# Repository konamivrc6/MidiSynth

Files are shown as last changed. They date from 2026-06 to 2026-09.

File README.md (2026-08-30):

# MidiSynth — ESP32-S3 MIDI 合成器

基于 ESP32-S3 的 12 复音双振荡器合成器，支持 USB MIDI 键盘输入、4 个硬件开关切换音色、串口实时调参。

## 硬件

| 模块 | 型号 | 接口 | 说明 |
|---|---|---|---|
| 主控 | ESP32-S3-DevKitC-1 (N16R8) | — | 双核 FreeRTOS |
| DAC | PCM5102 | I²S | 硬件模式，上电即工作 |
| 功放 | LM4881 | — | 纯硬件，无需代码控制 |
| 电位器 | — | ADC GPIO1 | 主音量调节 |
| 拨动开关 ×4 | — | GPIO10~13 | 二进制选择预设 (bit0~3) |
| 按钮 | — | GPIO14 | 加载当前开关对应的预设 |

### 引脚连接

```
I²S:   BCK → GPIO4,   LRCK → GPIO5,  DIN → GPIO6
ADC:   VR1 → GPIO1
开关:  SW1 → GPIO13 (bit0), SW2 → GPIO12 (bit1)
       SW3 → GPIO11 (bit2), SW4 → GPIO10 (bit3)
按钮:  BTN → GPIO14 (中断, FALLING)
```

所有开关和按钮使用 ESP32-S3 内部上拉，闭合时接 GND（低电平有效）。

## 软件架构

```
src/
├── config.h           # 全局类型定义、常量、extern 声明（所有 .inc 均包含此头文件）
├── config.inc         # 编译单元局部配置 + debugMode 定义（必须最先拼接）
├── presets.inc        # 16 种音色预设
├── audio_engine.inc   # 音频引擎（波形/包络/滤波器/复音管理/I²S 输出）
└── usb_midi.inc       # USB MIDI Host（接收外部 MIDI 键盘）
wavetables/
├── wavetables.h       # 分层波表常量与接口声明
├── wavetables.inc     # 自动生成的抗混叠波表数据（2048×11×6）
└── generate_wavetables.py  # 波表生成脚本
build.py               # 构建脚本（拼接 .inc → 单一 .cpp + 同步 config.h → .ino）
MidiSynth.ino          # Arduino 主文件（setup / loop / 串口命令）
```

### 音频引擎特性

- **双振荡器**：每个 Voice 包含 OSC1 + OSC2，可独立配置波形、音高倍数、音量、包络、滤波器路由
- **6 种波形**：Sine、Triangle、Pulse 1/8、Pulse 1/4、Pulse 1/2、Saw
- **ADSR 包络**：Attack / Decay / Sustain / Release，可独立配置 Attack 时间、Decay 时间、Sustain Level、Sustain 开关、Release 时间
- **双滤波器**：Filter1 高通 + Filter2 低通，一阶 IIR，可独立配置截止频率和强度
- **12 复音**：带智能 Voice 分配策略（同音符触发 Release → 空闲 → 衰减中 → 最早触发）
- **调试模式**：`debugMode` 变量控制启动信息、USB MIDI 诊断、性能报告的串口输出，可通过 `debug on/off` 切换，默认开启

## 依赖库

- **EspUsbHost** (by tanakamasayuki) — USB MIDI Host
- ESP32 Arduino Core（I²S、FreeRTOS）

## 构建

1. 修改 `src/` 下的源文件
2. 运行构建脚本：

```bash
python build.py                # 输出 MidiSynth_combined.cpp + 同步 config.h → .ino
python build.py -o out.cpp     # 输出到指定文件
python build.py --no-sync      # 仅拼接，不同步 .ino
```

3. 将 `MidiSynth.ino` 和 `MidiSynth_combined.cpp` 放在同一 Arduino 工程目录下
4. 用 Arduino IDE 编译上传

> **注意**：`build.py` 会自动将 `config.h` 中 `#define`/`enum`/`struct` 定义同步到 `.ino` 文件（匹配带有"(与 config.h 同步)"标记的区段）。修改 `config.h` 后运行 `build.py` 即可，无需手动同步。

## 使用

### 硬件操作

- **4 个拨动开关**：选择预设编号（二进制，SW1=bit0 ~ SW4=bit3，范围 0~15）
- **按钮**：加载当前开关对应的预设
- **电位器**：调节输出音量
- **右侧 USB**：连接 MIDI 键盘

### MIDI 文件播放

电脑端可通过串口将 `.mid` 文件实时发送给合成器播放。

**方式一：交互式播放器**

```bash
python play_midi.py
```

交互命令：

```
<数字>        播放对应编号的 MIDI 文件
port <COM号>  设置串口号 (如 port 3)
port auto     自动检测串口
port          列出所有可用串口
list          刷新 MIDI 文件列表
tempo <倍率>  播放速度倍率 (如 tempo 1.5)
trans <半音>  移调 (如 trans 12 升八度)
inst <0-15>   设置乐器预设
stop          发送 All Notes Off (紧急静音)
repeat <N> [次] 循环播放 (如 repeat 0 5)
/<命令>       发送原始串口命令 (如 /status)
help          显示帮助
quit / q      退出
```

MIDI 文件放在 `MIDI\` 目录下即可被自动扫描。

**方式二：命令行直接播放**

```bash
python MIDI\midi2serial.py <midi文件> [选项]

选项:
  --port COM3         串口输出
  --baud 115200       波特率 (默认 115200)
  --tempo 1.0         速度倍率
  --transpose N       移调 (半音)
  --preset N          乐器预设 0-15
  --save out.txt      将命令序列保存到文件
  --no-time           不显示时间戳

示例:
  python MIDI\midi2serial.py MIDI\song.mid --port COM3 --tempo 1.2
  python MIDI\midi2serial.py MIDI\song.mid --save cmds.txt  # 仅生成文件
```

### 串口命令（115200 baud）

```
note  <0-127> [vel=100]   — Note On（vel=0 即 Note Off）
off   <0-127>             — Note Off
preset <0-15>             — 加载预设

--- 振荡器参数 ---
o1wave <0-5>  o2wave <0-5>   — 波形: 0=Sine 1=Tri 2=P1/8 3=P1/4 4=P1/2 5=Saw
o1atk  <ms>    o2atk  <ms>    — Attack 时间 (ms)
o1sus  <0|1>   o2sus  <0|1>   — Sustain 开关
o1dec  <ms>    o2dec  <ms>    — Decay 时间 (ms)
o1slv  <0-1>   o2slv  <0-1>   — Sustain Level
o1rel  <ms>    o2rel  <ms>    — Release 时间 (ms)
o1vol  <0-1>   o2vol  <0-1>   — 音量
o1pm   <f>     o2pm   <f>     — 音高倍数 (2.0, 1.5, 1.0, 0.667, 0.5)
o1f1   <0|1>   o1f2   <0|1>   — OSC1 经 Filter1/2 路由
o2f1   <0|1>   o2f2   <0|1>   — OSC2 经 Filter1/2 路由

--- 滤波器参数 ---
hpfc <Hz>   hpfi <0-1>    — 高通截止频率 / 强度
lpfc <Hz>   lpfi <0-1>    — 低通截止频率 / 强度

--- 其他 ---
status                     — 打印当前参数
debug on/off               — 切换调试模式（控制启动日志/性能报告/USB诊断等输出）
help                       — 显示帮助
```

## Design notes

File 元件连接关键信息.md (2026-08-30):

* 去掉所有电阻、电容等无源器件后，**只保留与程序相关的关键连接**信息（含引脚编号、功能描述和必要的配置说明） *

## 一、主控芯片 ESP32‑S3（开发板 ESP32‑S3‑DevKitC‑1 N16R8）

### 1. I²S 音频输出（至 PCM5102 DAC）

```c
BCK  (位时钟)  → GPIO4
LRCK (左右时钟) → GPIO5
DIN  (数据)    → GPIO6
```

- PCM5102 工作在 **硬件模式**，无需 I²C 配置，只需 ESP32 端初始化 I²S 并连续发送 PCM 数据。

### 2. ADC 输入（电位器）

```c
VR1 滑动端 → GPIO1 (ADC1_CH0)
```

- 电位器两端分别接 3.3V 和 GND，模拟电压 0～3.3V，直接通过 `analogRead(1)` 读取（12 位 ADC 分辨率）。

### 3. 拨动开关（预设选择 ×4）

| GPIO | 网络名称 | 功能 | 软件配置 |
|---|---|---|---|
| GPIO13 | SW1 | 拨动开关 bit0 (值=1) | 输入模式，**使能内部上拉**（开关闭合接 GND） |
| GPIO12 | SW2 | 拨动开关 bit1 (值=2) | 输入模式，使能内部上拉 |
| GPIO11 | SW3 | 拨动开关 bit2 (值=4) | 输入模式，使能内部上拉 |
| GPIO10 | SW4 | 拨动开关 bit3 (值=8) | 输入模式，使能内部上拉 |

**读取示例：**

```cpp
uint8_t sw = 0;
if (!digitalRead(13)) sw |= 1;
if (!digitalRead(12)) sw |= 2;
if (!digitalRead(11)) sw |= 4;
if (!digitalRead(10)) sw |= 8;
// sw 范围 0~15，对应 16 种预设
```

### 4. 按钮（加载预设）

```c
按钮 → GPIO14
```

- 输入模式，**使能内部上拉**，按下为低电平。
- 配置为下降沿中断 (`FALLING`)，在中断服务中读取四个开关状态并加载对应预设。
- 软件消抖 200ms。

## 二、DAC 模块 PCM5102（纯硬件）

- **无需任何软件控制**，上电即工作。
- 使用的硬件接线：

`VCC` → 3.3V，`GND` → GND

`FLT`/`DMP`/`FMT` 已接地，`XMT`（静音）已接 3.3V（不静音）。

- 编程时只需关注 I²S 接口的 GPIO4/5/6。

## 三、耳机放大器 LM4881

- 纯硬件，**不需要代码控制**。

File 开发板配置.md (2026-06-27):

| 配置项 | 选择 |
|---|---|
| **USB CDC On Boot** | `Enabled` |
| **Flash Mode** | **`DIO`** |
| **Flash Size** | **`16MB`** |
| **PSRAM** | **`OPI PSRAM`** |
| **USB Mode** | `Hardware CDC and JTAG` |
| **Upload Mode** | `UART0 / Hardware CDC` |
| **Partition Scheme** | **`16M Flash (3M APP/9.9MB FATFS)`**|
| **CPU Frequency** | `240MHz (WiFi)` |
| **Upload Speed** | `921600` |
| **Erase All Flash Before Sketch Upload** | `Disabled` |

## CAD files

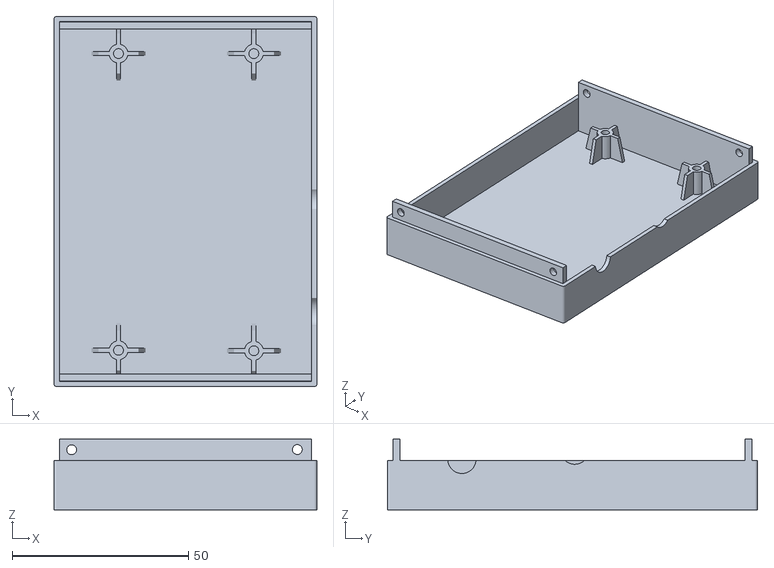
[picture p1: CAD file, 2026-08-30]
3D外壳/外壳顶层.stl
74.5 x 104.9 x 20.0

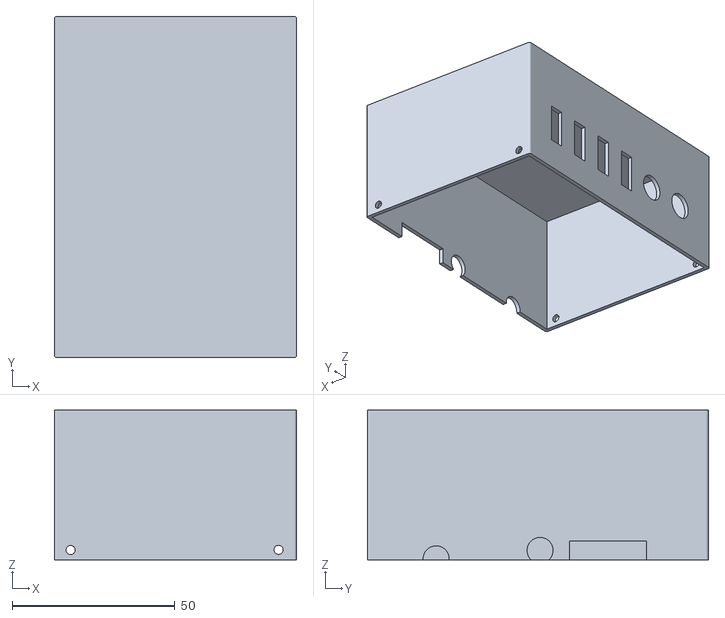
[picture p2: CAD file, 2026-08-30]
3D外壳/外壳底层.stl
74.5 x 104.9 x 46.0

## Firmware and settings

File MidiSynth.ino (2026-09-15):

/*
 * MidiSynth.ino — MIDI 合成器主文件
 * ESP32-S3 N16R8 + PCM5102 + LM4881
 *
 * 文件拼接顺序 (将所有 .cpp 拼接为一个文件):
 *   1. config.cpp       — 类型定义、常量、全局变量声明
 *   2. presets.cpp      — 16 种音色预设
 *   3. audio_engine.cpp — 音频引擎 (Voice、波形、滤波、包络)
 *   4. usb_midi.cpp     — USB MIDI Host
 *
 * 拼接后的 .cpp 与本 .ino 放在同一 Arduino 工程目录下即可。
 * 注意: 本 .ino 重复了部分 #define 和类型定义, 因为 .ino 是独立编译单元。
 */

#include <Arduino.h>
#include <freertos/FreeRTOS.h>
#include <freertos/queue.h>
#include <freertos/task.h>
#include "driver/i2s.h"

// 本板 Serial=USB CDC, Serial0=CP2102 UART, 用宏统一映射
#define Serial Serial0

// ======================== 引脚定义 (与 config.h 同步) ========================
#define PIN_I2S_BCK       4
#define PIN_I2S_LRCK      5
#define PIN_I2S_DIN       6
#define PIN_ADC_VOLUME    1
#define PIN_SW1          13
#define PIN_SW2          12
#define PIN_SW3          11
#define PIN_SW4          10
#define PIN_BUTTON       14

// ======================== 音频参数 (与 config.h 同步) ========================
#define SAMPLE_RATE       44100
#define BUFFER_FRAMES      256
#define MAX_POLYPHONY       12
#define MIDI_QUEUE_SIZE     32
#define PARAM_QUEUE_SIZE    16

// ======================== 预设开关引脚映射 (与 config.h 同步) ========================
// 四个拨动开关 GPIO10~13, 内部上拉, 闭合=低电平
// SW1=bit0(1) 在 GPIO13, SW2=bit1(2) 在 GPIO12, SW3=bit2(4) 在 GPIO11, SW4=bit3(8) 在 GPIO10
// 按钮在 GPIO14, 按钮/开关接线与代码注释以实际硬件为准
// PIN_SW1~4 已在 "引脚定义" 区段中定义

// ======================== 消息类型 (与 config.h 同步) ========================
enum MsgType : uint8_t {
    MSG_NOTE_ON     = 0,
    MSG_NOTE_OFF    = 1,
    MSG_LOAD_PRESET = 2
};

struct MidiMsg {
    MsgType type;
    uint8_t data1;
    uint8_t data2;
};

// ======================== 参数 ID (与 config.h 同步) ========================
enum ParamId : uint8_t {
    PARAM_O1_WAVEFORM = 0,
    PARAM_O2_WAVEFORM,
    PARAM_O1_ATTACK,
    PARAM_O2_ATTACK,
    PARAM_O1_SUSTAIN,
    PARAM_O2_SUSTAIN,
    PARAM_O1_RELEASE,
    PARAM_O2_RELEASE,
    PARAM_O1_DECAY_TIME,
    PARAM_O2_DECAY_TIME,
    PARAM_O1_SUSTAIN_LV,
    PARAM_O2_SUSTAIN_LV,
    PARAM_O1_VOLUME,
    PARAM_O2_VOLUME,
    PARAM_O1_PITCHMUL,
    PARAM_O2_PITCHMUL,
    PARAM_O1_USEF1,
    PARAM_O1_USEF2,
    PARAM_O2_USEF1,
    PARAM_O2_USEF2,
    PARAM_F1_CUTOFF,
    PARAM_F1_INTENSITY,
    PARAM_F2_CUTOFF,
    PARAM_F2_INTENSITY,
};

struct ParamCmd {
    uint8_t param_id;
    float   value;
};

struct TaskParams {
    QueueHandle_t midiQueue;
    QueueHandle_t paramQueue;
};

// ======================== 外部声明 ========================
extern QueueHandle_t midiQueue;
extern QueueHandle_t paramQueue;
extern volatile bool buttonISRflag;
extern bool debugMode;

extern void audio_task(void *param);
extern void loadPreset(uint8_t idx);
extern void printAudioStatus();
extern void initUSBMidi();

// ======================== 消抖计时 ========================
static uint32_t lastButtonTime = 0;

// ======================== 串口命令缓冲区 ========================
static char  serialBuf[64];
static int   serialIdx = 0;

// ======================== 电位器读取 ========================
float readVolume() {
    int raw = analogRead(PIN_ADC_VOLUME);
    static float smooth = 0.0f;
    smooth += 0.05f * (raw / 4095.0f - smooth);
    return smooth;
}

// ======================== 按钮中断 ISR ========================
void IRAM_ATTR buttonISR() {
    buttonISRflag = true;
}

// ======================== 串口命令处理 ========================
static void sendParam(uint8_t id, float val) {
    ParamCmd pc;
    pc.param_id = id;
    pc.value    = val;
    xQueueSend(paramQueue, &pc, 0);
}

static void printHelp() {
    Serial.println(F("\n===== 串口调试命令 ====="));
    Serial.println(F(" note  <0-127> [vel=100]  — 发送 Note On (vel=0 即 Note Off)"));
    Serial.println(F(" off   <0-127>           — 发送 Note Off"));
    Serial.println(F(" preset <0-15>            — 加载预设"));
    Serial.println(F("--- 振荡器参数 (o1=OSC1, o2=OSC2) ---"));
    Serial.println(F(" o1wave <0-5>  o2wave <0-5>  — 波形: 0=Sine 1=Tri 2=P1/8 3=P1/4 4=P1/2 5=Saw"));
    Serial.println(F(" o1atk  <ms>    o2atk  <ms>    — Attack 时间"));
    Serial.println(F(" o1sus  <0|1>   o2sus  <0|1>   — Sustain 开关"));
    Serial.println(F(" o1dec  <ms>    o2dec  <ms>    — Decay 时间"));
    Serial.println(F(" o1slv  <0-1>   o2slv  <0-1>   — Sustain Level"));
    Serial.println(F(" o1rel  <ms>    o2rel  <ms>    — Release 时间"));
    Serial.println(F(" o1vol  <0-1>   o2vol  <0-1>   — 音量"));
    Serial.println(F(" o1pm   <f>     o2pm   <f>     — 音高倍数"));
    Serial.println(F(" o1f1   <0|1>   o1f2   <0|1>   — OSC1 经 Filter1/2"));
    Serial.println(F(" o2f1   <0|1>   o2f2   <0|1>   — OSC2 经 Filter1/2"));
    Serial.println(F("--- 滤波器参数 ---"));
    Serial.println(F(" hpfc <Hz>   hpfi <0-1>     — 高通截止频率 / 强度"));
    Serial.println(F(" lpfc <Hz>   lpfi <0-1>     — 低通截止频率 / 强度"));
    Serial.println(F("--- 其他 ---"));
    Serial.println(F(" status                     — 打印当前参数"));
    Serial.println(F(" debug on/off               — 切换调试模式"));
    Serial.println(F(" help                       — 显示此帮助"));
    Serial.println(F("===========================\n"));
}

static void parseCommand(char *cmd) {
    // 跳过前导空白
    while (*cmd == ' ' || *cmd == '\t') cmd++;
    if (*cmd == '\0') return;

    char *space = strchr(cmd, ' ');
    if (!space) {
        // 无参数命令
        if (strcmp(cmd, "help") == 0) {
            printHelp();
        } else if (strcmp(cmd, "status") == 0) {
            printAudioStatus();
        } else {
            Serial.printf("未知命令: '%s'  输入 help 查看帮助\n", cmd);
        }
        return;
    }

    *space = '\0';
    char *arg1 = space + 1;
    while (*arg1 == ' ' || *arg1 == '\t') arg1++;

    // 找第二个参数
    char *arg2 = strchr(arg1, ' ');
    if (arg2) {
        *arg2 = '\0';
        arg2++;
        while (*arg2 == ' ' || *arg2 == '\t') arg2++;
    }

    // ---- 音符命令 ----
    if (strcmp(cmd, "note") == 0) {
        int note = atoi(arg1);
        int vel  = arg2 ? atoi(arg2) : 100;
        if (note < 0 || note > 127) { Serial.println("音符范围: 0-127"); return; }
        MidiMsg msg;
        if (vel > 0) {
            msg.type = MSG_NOTE_ON;
            msg.data1 = note;
            msg.data2 = (vel > 127) ? 127 : vel;
        } else {
            msg.type = MSG_NOTE_OFF;
            msg.data1 = note;
            msg.data2 = 0;
        }
        xQueueSend(midiQueue, &msg, 0);
        Serial.printf("Note %s  ch=%d vel=%d\n", (vel > 0) ? "ON" : "OFF", note, vel);
        return;
    }
    if (strcmp(cmd, "off") == 0) {
        int note = atoi(arg1);
        if (note < 0 || note > 127) { Serial.println("音符范围: 0-127"); return; }
        MidiMsg msg = {MSG_NOTE_OFF, (uint8_t)note, 0};
        xQueueSend(midiQueue, &msg, 0);
        Serial.printf("Note OFF  ch=%d\n", note);
        return;
    }

    // ---- 预设命令 ----
    if (strcmp(cmd, "preset") == 0) {
        int idx = atoi(arg1);
        if (idx < 0 || idx > 15) { Serial.println("预设范围: 0-15"); return; }
        MidiMsg msg = {MSG_LOAD_PRESET, (uint8_t)idx, 0};
        xQueueSend(midiQueue, &msg, 0);
        Serial.printf("加载预设 #%d\n", idx);
        return;
    }

    // ---- 参数命令映射 ----
    struct ParamMap { const char *name; uint8_t id; };
    static const ParamMap map[] = {
        {"o1wave", PARAM_O1_WAVEFORM}, {"o2wave", PARAM_O2_WAVEFORM},
        {"o1atk",  PARAM_O1_ATTACK},   {"o2atk",  PARAM_O2_ATTACK},
        {"o1sus",  PARAM_O1_SUSTAIN},  {"o2sus",  PARAM_O2_SUSTAIN},
        {"o1rel",  PARAM_O1_RELEASE},  {"o2rel",  PARAM_O2_RELEASE},
        {"o1dec",  PARAM_O1_DECAY_TIME}, {"o2dec",  PARAM_O2_DECAY_TIME},
        {"o1slv",  PARAM_O1_SUSTAIN_LV}, {"o2slv",  PARAM_O2_SUSTAIN_LV},
        {"o1vol",  PARAM_O1_VOLUME},   {"o2vol",  PARAM_O2_VOLUME},
        {"o1pm",   PARAM_O1_PITCHMUL}, {"o2pm",   PARAM_O2_PITCHMUL},
        {"o1f1",   PARAM_O1_USEF1},    {"o1f2",   PARAM_O1_USEF2},
        {"o2f1",   PARAM_O2_USEF1},    {"o2f2",   PARAM_O2_USEF2},
        {"hpfc",   PARAM_F1_CUTOFF},   {"hpfi",   PARAM_F1_INTENSITY},
        {"lpfc",   PARAM_F2_CUTOFF},   {"lpfi",   PARAM_F2_INTENSITY},
    };

    for (auto &m : map) {
        if (strcmp(cmd, m.name) == 0) {
            float val = atof(arg1);
            sendParam(m.id, val);
            Serial.printf("%s = %.3f\n", m.name, val);
            return;
        }
    }

    // ---- debug 命令 ----
    if (strcmp(cmd, "debug") == 0) {
        if (strcmp(arg1, "on") == 0) {
            debugMode = true;
            Serial.println("调试模式: 开启");
        } else if (strcmp(arg1, "off") == 0) {
            debugMode = false;
            Serial.println("调试模式: 关闭");
        } else {
            Serial.printf("调试模式当前: %s  用法: debug on / debug off\n",
                          debugMode ? "开启" : "关闭");
        }
        return;
    }

    Serial.printf("未知命令: '%s'  输入 help 查看帮助\n", cmd);
}

static void processSerial() {
    while (Serial.available()) {
        char c = Serial.read();
        if (c == '\n' || c == '\r') {
            if (serialIdx > 0) {
                serialBuf[serialIdx] = '\0';
                parseCommand(serialBuf);
                serialIdx = 0;
            }
        } else if (serialIdx < (int)sizeof(serialBuf) - 1) {
            serialBuf[serialIdx++] = c;
        }
    }
}

// ======================== setup ========================
void setup() {
    Serial.begin(115200);
    delay(500);
    if (debugMode) Serial.println("\n[MidiSynth] 启动中...");

    // 1. 初始化 I2S (PCM5102, 硬件模式, Master TX)
    i2s_config_t i2s_cfg;
    memset(&i2s_cfg, 0, sizeof(i2s_cfg));
    i2s_cfg.mode                 = (i2s_mode_t)(I2S_MODE_MASTER | I2S_MODE_TX);
    i2s_cfg.sample_rate          = SAMPLE_RATE;
    i2s_cfg.bits_per_sample      = I2S_BITS_PER_SAMPLE_16BIT;
    i2s_cfg.channel_format       = I2S_CHANNEL_FMT_RIGHT_LEFT;
    i2s_cfg.communication_format = I2S_COMM_FORMAT_STAND_I2S;
    i2s_cfg.intr_alloc_flags     = ESP_INTR_FLAG_LEVEL1;
    i2s_cfg.dma_buf_count        = 8;
    i2s_cfg.dma_buf_len          = BUFFER_FRAMES;
    i2s_cfg.use_apll             = false;
    i2s_cfg.tx_desc_auto_clear   = true;
    i2s_cfg.fixed_mclk           = 0;

    i2s_pin_config_t pin_cfg;
    memset(&pin_cfg, 0, sizeof(pin_cfg));
    pin_cfg.bck_io_num     = PIN_I2S_BCK;
    pin_cfg.ws_io_num      = PIN_I2S_LRCK;
    pin_cfg.data_out_num   = PIN_I2S_DIN;
    pin_cfg.data_in_num    = I2S_PIN_NO_CHANGE;

    i2s_driver_install(I2S_NUM_0, &i2s_cfg, 0, NULL);
    i2s_set_pin(I2S_NUM_0, &pin_cfg);
    if (debugMode) Serial.println("[I2S] 已初始化 (44100 Hz, 16-bit, 立体声)");

    // 2. 创建消息队列
    midiQueue = xQueueCreate(MIDI_QUEUE_SIZE, sizeof(MidiMsg));
    paramQueue = xQueueCreate(PARAM_QUEUE_SIZE, sizeof(ParamCmd));
    if (!midiQueue || !paramQueue) {
        Serial.println("[FATAL] 队列创建失败");
        return;
    }

    // 3. 创建音频任务 (Core 1, 高优先级)
    static TaskParams tp;
    tp.midiQueue  = midiQueue;
    tp.paramQueue = paramQueue;
    xTaskCreatePinnedToCore(
        audio_task,
        "audio",
        8192,
        &tp,
        configMAX_PRIORITIES - 1,
        NULL,
        1
    );
    if (debugMode) Serial.println("[Task] 音频任务已创建 (Core 1)");

    // 4. 发送初始预设加载消息
    MidiMsg initMsg;
    initMsg.type  = MSG_LOAD_PRESET;
    initMsg.data1 = 0;
    initMsg.data2 = 0;
    xQueueSend(midiQueue, &initMsg, portMAX_DELAY);

    // 5. 初始化 USB MIDI Host
    initUSBMidi();

    // 6. 配置 GPIO 输入 (内部上拉, 闭合=低电平)
    pinMode(PIN_SW1, INPUT_PULLUP);
    pinMode(PIN_SW2, INPUT_PULLUP);
    pinMode(PIN_SW3, INPUT_PULLUP);
    pinMode(PIN_SW4, INPUT_PULLUP);
    pinMode(PIN_BUTTON, INPUT_PULLUP);
    attachInterrupt(PIN_BUTTON, buttonISR, FALLING);
    if (debugMode) Serial.println("[GPIO] 中断已配置 (GPIO14, FALLING)");

    // 7. 设置 ADC 分辨率
    analogReadResolution(12);

    if (debugMode) {
        Serial.println("[MidiSynth] 就绪!");
        Serial.println("  四个开关: 选择预设 (0-15)");
        Serial.println("  按钮:     加载当前开关对应的预设");
        Serial.println("  电位器:   调节输出音量");
        Serial.println("  右侧 USB: 连接 MIDI 键盘");
        Serial.println("  串口:     输入 help 查看调试命令");
    }
}

// ======================== loop ========================
void loop() {
    // 1. 串口命令处理
    processSerial();

    // 2. 按钮中断处理
    if (buttonISRflag) {
        buttonISRflag = false;

        uint32_t now = millis();
        if (now - lastButtonTime > 200) {
            // 按钮按下=低电平 (内部上拉)
            if (!digitalRead(PIN_BUTTON)) {
                uint8_t sw = 0;
                if (!digitalRead(PIN_SW1)) sw |= 1;
                if (!digitalRead(PIN_SW2)) sw |= 2;
                if (!digitalRead(PIN_SW3)) sw |= 4;
                if (!digitalRead(PIN_SW4)) sw |= 8;

                MidiMsg msg;
                msg.type  = MSG_LOAD_PRESET;
                msg.data1 = sw;
                msg.data2 = 0;
                xQueueSend(midiQueue, &msg, 0);

                if (debugMode) {
                    Serial.print("[Preset] 加载预设 #");
                    Serial.println(sw);
                }
            }
            lastButtonTime = now;
        }
    }

    delay(10);
}

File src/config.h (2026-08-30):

/*
 * config.h — 全局类型定义、常量、外部声明
 * 所有 .cpp 文件独立编译时均需包含此头文件。
 */

#ifndef CONFIG_H
#define CONFIG_H

#include <Arduino.h>
#include <freertos/FreeRTOS.h>
#include <freertos/queue.h>
#include <freertos/task.h>
#include "driver/i2s.h"
#include <stdint.h>

// ======================== 引脚定义 ========================
#define PIN_I2S_BCK       4
#define PIN_I2S_LRCK      5
#define PIN_I2S_DIN       6
#define PIN_ADC_VOLUME    1
#define PIN_SW1          13
#define PIN_SW2          12
#define PIN_SW3          11
#define PIN_SW4          10
#define PIN_BUTTON       14

// ======================== 音频参数 ========================
#define SAMPLE_RATE       44100
#define BUFFER_FRAMES      256
#define MAX_POLYPHONY       12
#define MIDI_QUEUE_SIZE     32
#define PARAM_QUEUE_SIZE    16

// ======================== 预设开关引脚映射 ========================
// 四个拨动开关 GPIO10~13, 内部上拉, 闭合=低电平
// SW1=bit0(1) 在 GPIO13, SW2=bit1(2) 在 GPIO12, SW3=bit2(4) 在 GPIO11, SW4=bit3(8) 在 GPIO10
// 按钮在 GPIO14, 按钮/开关接线与代码注释以实际硬件为准
// PIN_SW1~4 已在 "引脚定义" 区段中定义

// ======================== 波形枚举 ========================
enum Waveform : uint8_t {
    WAVE_SINE      = 0,
    WAVE_TRI       = 1,
    WAVE_PULSE_1_8 = 2,
    WAVE_PULSE_1_4 = 3,
    WAVE_PULSE_1_2 = 4,
    WAVE_SAW       = 5
};

// ======================== 消息类型 ========================
enum MsgType : uint8_t {
    MSG_NOTE_ON     = 0,
    MSG_NOTE_OFF    = 1,
    MSG_LOAD_PRESET = 2
};

struct MidiMsg {
    MsgType type;
    uint8_t data1;
    uint8_t data2;
};

// ======================== 参数调整命令 ========================
enum ParamId : uint8_t {
    PARAM_O1_WAVEFORM = 0,
    PARAM_O2_WAVEFORM,
    PARAM_O1_ATTACK,
    PARAM_O2_ATTACK,
    PARAM_O1_SUSTAIN,
    PARAM_O2_SUSTAIN,
    PARAM_O1_RELEASE,
    PARAM_O2_RELEASE,
    PARAM_O1_DECAY_TIME,
    PARAM_O2_DECAY_TIME,
    PARAM_O1_SUSTAIN_LV,
    PARAM_O2_SUSTAIN_LV,
    PARAM_O1_VOLUME,
    PARAM_O2_VOLUME,
    PARAM_O1_PITCHMUL,
    PARAM_O2_PITCHMUL,
    PARAM_O1_USEF1,
    PARAM_O1_USEF2,
    PARAM_O2_USEF1,
    PARAM_O2_USEF2,
    PARAM_F1_CUTOFF,
    PARAM_F1_INTENSITY,
    PARAM_F2_CUTOFF,
    PARAM_F2_INTENSITY,
};

struct ParamCmd {
    uint8_t param_id;
    float   value;
};

// ======================== 音频任务参数 ========================
struct TaskParams {
    QueueHandle_t midiQueue;
    QueueHandle_t paramQueue;
};

// ======================== 包络状态机 ========================
enum EnvState : uint8_t {
    ENV_OFF     = 0,
    ENV_ATTACK  = 1,
    ENV_DECAY   = 2,
    ENV_SUSTAIN = 3,
    ENV_RELEASE = 4
};

struct Envelope {
    float level;
    float delta;
    EnvState state;
    float attackDelta;
    float decayDelta;
    float releaseDelta;
    float sustainLv;
    bool  sustain;
};

// ======================== 振荡器参数 (存储在预设中) ========================
struct OscParams {
    uint8_t  waveform;
    uint16_t attack_ms;
    bool     sustain;
    uint16_t decayTime;
    float    sustainLv;
    uint16_t release_ms;
    float    volume;
    float    pitchMul;
    bool     useFilter1;
    bool     useFilter2;
};

// ======================== 滤波器参数 (存储在预设中) ========================
struct FilterParams {
    float fc;
    float intensity;
};

// ======================== 预设 ========================
struct Preset {
    OscParams    osc1;
    OscParams    osc2;
    FilterParams filter1;
    FilterParams filter2;
};

// ======================== 振荡器运行时状态 ========================
struct OscVoice {
    uint8_t waveform;
    float   volume;
    float   pitchMul;
    bool    useFilter1;
    bool    useFilter2;
    float   filt1_alpha;
    float   filt1_intensity;
    float   filt2_alpha;
    float   filt2_intensity;

    float    phase;
    float    phaseDelta;        // 预计算: baseFreq / SAMPLE_RATE, 消除每采样点浮点除法
    float    baseFreq;
    const int16_t *wt_table0;   // 缓存: 主波表层指针
    const int16_t *wt_table1;   // 缓存: 次波表层指针 (与 table0 相同时跳过层间插值)
    float    wt_frac;           // 层间插值因子
    Envelope env;

    float lp1_state;
    float lp2_state;
};

// ======================== 复音 Voice ========================
struct Voice {
    bool     active;
    uint8_t  note;
    float    velocityScale;
    OscVoice osc1;
    OscVoice osc2;
    uint32_t noteOnTime;
};

// ======================== 全局变量 extern ========================
extern QueueHandle_t midiQueue;
extern QueueHandle_t paramQueue;

extern Voice voices[MAX_POLYPHONY];

extern Preset currentPreset;
extern float  currentFilter1_alpha;
extern float  currentFilter2_alpha;

extern volatile bool buttonISRflag;
bool debugMode = true;

extern const Preset presets[16];

extern uint32_t sampleCounter;

// ======================== 函数声明 ========================
void audio_task(void *param);
void loadPreset(uint8_t idx);
void printAudioStatus();

void initUSBMidi();

void initNoteToLayer();
float lookupWavetable(uint8_t waveform, float phase, float layerFloat);

float readVolume();

#endif

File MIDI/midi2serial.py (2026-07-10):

"""
midi2serial.py — 将 MIDI 文件转换为 MidiSynth 串口调试命令。

用法:
    python midi2serial.py <midi_file> [选项]

    --port COM3       串口输出 (不指定则打印到 stdout)
    --baud 115200     波特率 (默认 115200)
    --tempo 1.0       速度倍率 (默认 1.0, 2.0=双倍速)
    --save out.txt    将命令序列保存到文件 (含时间戳)
    --no-time         输出不带延时信息的纯命令列表
    --channel 0       只处理指定 MIDI 通道 (默认全部)
    --transpose N     移调 (半音, 默认 0)
    --preset N        乐器预设 0-15 (默认 0)

示例:
    python midi2serial.py the-entertainer.mid --save cmds.txt
    python midi2serial.py the-entertainer.mid --port COM3 --tempo 1.2
    python midi2serial.py the-entertainer.mid --transpose 12   # 升八度
"""

import sys
import time
import argparse
from collections import defaultdict


def parse_midi(path):
    """读取 MIDI 文件，返回 (ticks_per_beat, 排序后的事件列表)。

    每个事件: (abs_tick, 'note_on'|'note_off', note, velocity)
    同时读取 tempo map, 返回为 [(abs_tick, tempo_microseconds_per_beat), ...]
    """
    try:
        import mido
    except ImportError:
        print("[错误] 需要安装 mido: pip install mido", file=sys.stderr)
        sys.exit(1)

    mid = mido.MidiFile(path)
    tpb = mid.ticks_per_beat

    events = []       # (abs_tick, type, note, velocity)
    tempo_map = []    # (abs_tick, tempo)

    for track in mid.tracks:
        abs_tick = 0
        for msg in track:
            abs_tick += msg.time

            if msg.type == 'set_tempo':
                tempo_map.append((abs_tick, msg.tempo))

            elif msg.type == 'note_on':
                if msg.velocity > 0:
                    events.append((abs_tick, 'note_on', msg.note, msg.velocity))
                else:
                    events.append((abs_tick, 'note_off', msg.note, 0))

            elif msg.type == 'note_off':
                events.append((abs_tick, 'note_off', msg.note, 0))

    events.sort(key=lambda e: e[0])
    tempo_map.sort(key=lambda t: t[0])

    if not tempo_map:
        tempo_map = [(0, 500000)]  # 默认 120 BPM

    return tpb, events, tempo_map


def build_time_function(tpb, tempo_map):
    """根据 tempo map 构建 tick → 秒 的转换。返回 callable(tick) -> seconds。

    实现方式: 预计算每个 tempo 区段的起止 tick 和时长。
    """
    segments = []

    for i, (tick, tempo) in enumerate(tempo_map):
        next_tick = tempo_map[i + 1][0] if i + 1 < len(tempo_map) else None
        # tempo 单位: 微秒每拍, 转换: tick / tpb * tempo / 1e6 = 秒
        seconds_per_tick_at_this_tempo = tempo / 1e6 / tpb
        segments.append((tick, next_tick, seconds_per_tick_at_this_tempo))

    def tick_to_seconds(target_tick):
        elapsed = 0.0
        for start_tick, end_tick, spt in segments:
            if target_tick <= start_tick:
                break
            seg_end = end_tick if end_tick is not None else target_tick
            if seg_end > target_tick:
                seg_end = target_tick
            if seg_end > start_tick:
                elapsed += (seg_end - start_tick) * spt
        return elapsed

    return tick_to_seconds


def filter_events(events, channel, transpose):
    """按通道过滤、移调。channel=None 表示全部。"""
    result = []
    for abs_tick, etype, note, velocity in events:
        # MIDI 通道过滤: note 本身不携带通道, 通道信息在原始 msg.channel 上
        # 但我们从合并后的 track 中提取时丢失了通道。
        # 实际使用中大多数单轨 MIDI 无需过滤。
        # 如果需要通道过滤, 需在 parse 阶段保留 channel。
        new_note = note + transpose
        if 0 <= new_note <= 127:
            result.append((abs_tick, etype, new_note, velocity))
    return result


def generate_commands(events, to_seconds, tempo_mult, preset):
    """生成 (relative_seconds, command_string) 序列。

    同 tick 的 note_off 排在 note_on 之前，避免同一音符先触发再关闭的瞬间冲突。
    """
    # 首先发送预设加载命令
    yield (0.0, f"preset {preset}")

    # 按 (abs_tick, 优先级) 排序: note_off(0) 先于 note_on(1)
    priority = {'note_off': 0, 'note_on': 1}
    sorted_events = sorted(events, key=lambda e: (e[0], priority.get(e[1], 0)))

    prev_sec = 0.0

    for abs_tick, etype, note, velocity in sorted_events:
        sec = to_seconds(abs_tick) / tempo_mult
        delay = sec - prev_sec
        prev_sec = sec

        if etype == 'note_on':
            cmd = f"note {note} {velocity}"
        else:
            cmd = f"off {note}"

        yield (delay, cmd)


def output_to_stdout(commands, show_time):
    """打印到 stdout。"""
    last_sec = 0.0
    for delay, cmd in commands:
        last_sec += delay
        if show_time:
            print(f"[{last_sec:8.3f}s]  {cmd}")
        else:
            print(cmd)


def output_to_file(commands, path, show_time):
    """保存到文件。"""
    with open(path, 'w', encoding='utf-8') as f:
        last_sec = 0.0
        for delay, cmd in commands:
            last_sec += delay
            if show_time:
                f.write(f"[{last_sec:8.3f}s]  {cmd}\n")
            else:
                f.write(f"{cmd}\n")
    print(f"[保存] {path}")


def output_to_serial(commands, port, baud):
    """通过串口实时发送命令。"""
    try:
        import serial
    except ImportError:
        print("[错误] 需要安装 pyserial: pip install pyserial", file=sys.stderr)
        sys.exit(1)

    ser = serial.Serial(port, baud, timeout=1)
    print(f"[串口] {port} @ {baud} 已连接")

    total_commands = sum(1 for _ in commands)
    # 重新生成迭代器, 因为之前可能被消耗了
    print(f"[播放] 共 {total_commands} 条命令")

    # 这里需要重新从生成器获取 — 调用者会传入新的迭代器
    # 所以我们在这个函数里不再接收 commands, 而是在 main 中处理

    ser.close()
    raise NotImplementedError("串口输出需在 main 中实现以复用 commands 迭代器")
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

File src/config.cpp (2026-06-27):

/*
 * config.cpp — 全局数据结构、常量、引脚定义、全局变量
 * 此文件应在拼接所有 .cpp 时置于最前面
 * MidiSynth for ESP32-S3 N16R8
 */

#include <Arduino.h>
#include <freertos/FreeRTOS.h>
#include <freertos/queue.h>
#include <freertos/task.h>
#include "driver/i2s.h"
#include "esp_timer.h"

// 本板 Serial=USB CDC, Serial0=CP2102 UART
#define Serial Serial0

// ======================== 引脚定义 ========================
#define PIN_I2C_SCL      48
#define PIN_I2C_SDA      21
#define PIN_I2S_BCK       4
#define PIN_I2S_LRCK      5
#define PIN_I2S_DIN       6
#define PIN_ADC_VOLUME    7     // ADC1_CH6, 电位器
#define PIN_MCP_INTA     13     // 外部中断, 来自 MCP23017 INTA

// ======================== 音频参数 ========================
#define SAMPLE_RATE       44100
#define BUFFER_FRAMES      256   // 每次处理的帧数 (立体声 = *2)
#define MAX_POLYPHONY       16
#define MIDI_QUEUE_SIZE     32
#define PARAM_QUEUE_SIZE    16

// ======================== MCP23017 寄存器地址 (BANK=0) ========================
#define MCP_ADDR          0x20  // A0=A1=A2=GND
#define MCP_IODIRB        0x01
#define MCP_GPPUB         0x0D
#define MCP_IOCON         0x0A
#define MCP_GPINTENB      0x05
#define MCP_INTCONB       0x09
#define MCP_GPIOB         0x13

// ======================== 预设开关引脚映射 ========================
// GPB2=SW1, GPB3=SW2, GPB4=SW3, GPB5=SW4, GPB6=BUTTON
#define MCP_SW_MASK       0x3C  // bits 2-5
#define MCP_SW_SHIFT         2
#define MCP_BTN_MASK      0x40  // bit 6

// ======================== 波形枚举 ========================
enum Waveform : uint8_t {
    WAVE_SINE      = 0,
    WAVE_TRI       = 1,
    WAVE_PULSE_1_8 = 2,
    WAVE_PULSE_1_4 = 3,
    WAVE_PULSE_1_2 = 4,
    WAVE_SAW       = 5
};

// ======================== 消息类型 ========================
enum MsgType : uint8_t {
    MSG_NOTE_ON     = 0,
    MSG_NOTE_OFF    = 1,
    MSG_LOAD_PRESET = 2
};

struct MidiMsg {
    MsgType type;
    uint8_t data1;   // note 或 preset_index
    uint8_t data2;   // velocity
};

// ======================== 参数调整命令 ========================
enum ParamId : uint8_t {
    PARAM_O1_WAVEFORM = 0,
    PARAM_O2_WAVEFORM,
    PARAM_O1_ATTACK,
    PARAM_O2_ATTACK,
    PARAM_O1_SUSTAIN,
    PARAM_O2_SUSTAIN,
    PARAM_O1_RELEASE,
    PARAM_O2_RELEASE,
    PARAM_O1_VOLUME,
    PARAM_O2_VOLUME,
    PARAM_O1_PITCHMUL,
    PARAM_O2_PITCHMUL,
    PARAM_O1_USEF1,
    PARAM_O1_USEF2,
    PARAM_O2_USEF1,
    PARAM_O2_USEF2,
    PARAM_F1_CUTOFF,
    PARAM_F1_INTENSITY,
    PARAM_F2_CUTOFF,
    PARAM_F2_INTENSITY,
};

struct ParamCmd {
    uint8_t param_id;
    float   value;
};

// ======================== 音频任务参数 ========================
struct TaskParams {
    QueueHandle_t midiQueue;
    QueueHandle_t paramQueue;
};

// ======================== 包络状态机 ========================
enum EnvState : uint8_t {
    ENV_OFF     = 0,
    ENV_ATTACK  = 1,
    ENV_SUSTAIN = 2,
    ENV_RELEASE = 3
};

struct Envelope {
    float level;
    float delta;
    EnvState state;
    float attackDelta;
    float releaseDelta;
    bool  sustain;
};

// ======================== 振荡器参数 (存储在预设中) ========================
struct OscParams {
    uint8_t  waveform;     // Waveform 枚举值 0-5
    uint16_t attack_ms;
    bool     sustain;
    uint16_t release_ms;
    float    volume;       // 0.0 ~ 1.0
    float    pitchMul;     // 频率倍数: 2, 1.5, 1, 0.666667, 0.5
    bool     useFilter1;   // 是否经过高通
    bool     useFilter2;   // 是否经过低通
};

// ======================== 滤波器参数 (存储在预设中) ========================
struct FilterParams {
    float fc;              // 截止频率 (Hz)
    float intensity;       // 0.0 ~ 1.0
};

// ======================== 预设 ========================
struct Preset {
    OscParams    osc1;
    OscParams    osc2;
    FilterParams filter1;  // 高通
    FilterParams filter2;  // 低通
};

// ======================== 振荡器运行时状态 ========================
struct OscVoice {
    // 静态参数 (从预设拷贝)
    uint8_t waveform;
    float   volume;
    float   pitchMul;
    bool    useFilter1;
    bool    useFilter2;
    float   filt1_alpha;
    float   filt1_intensity;
    float   filt2_alpha;
    float   filt2_intensity;

    // 动态状态
    float    phase;
    float    baseFreq;
    Envelope env;

    // 一阶滤波器记忆
    float lp1_state;
    float lp2_state;
};

// ======================== 复音 Voice ========================
struct Voice {
    bool     active;
    uint8_t  note;
    float    velocityScale;  // velocity / 127.0
    OscVoice osc1;
    OscVoice osc2;
    uint32_t noteOnTime;     // 用于替换策略 (采样计数)
};

// ======================== 全局变量 ========================
extern QueueHandle_t midiQueue;
extern QueueHandle_t paramQueue;

extern Voice voices[MAX_POLYPHONY];

extern Preset currentPreset;
extern float  currentFilter1_alpha;
extern float  currentFilter2_alpha;

extern volatile bool buttonISRflag;

extern const Preset presets[16];

extern uint32_t sampleCounter;

// ======================== 函数声明 ========================
void initMCP23017();
uint8_t readMCP23017_GPIOB();

void audio_task(void *param);
void loadPreset(uint8_t idx);
void printAudioStatus();
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

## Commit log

2026-07-10 将 concat.py 重命名为 build.py，增加 config.h → .ino 自动同步功能
    - 重命名 concat.py → build.py，更新所有引用
    - build.py 新增 sync_ino()：自动将 config.h 中 5 个区段的 #define/enum/struct 定义同步到 MidiSynth.ino
    - 修复 audio_engine.inc 中性能日志硬编码的复音数（12 → MAX_POLYPHONY）
    - 更新 README 构建章节
    [MidiSynth.ino, build.py]
2026-07-10 add debugMode flag to gate diagnostic serial output
    Introduce a `debugMode` bool (default true) in config.h to control
    verbose serial output. Startup messages, USB MIDI diagnostics,
    performance reports, status dumps, and button preset logs are now
    gated behind `if (debugMode)`. FATAL errors and interactive command
    responses (help, note on/off feedback) remain unconditional.
    A `debug on` / `debug off` serial command allows runtime toggling.
    [MidiSynth.ino, config.h]
2026-07-10 replace MCP23017 GPIO expander with direct GPIO connections
    Switches (GPIO11-14) and button (GPIO10) now connect directly to
    the ESP32-S3 with internal pull-ups, replacing the I²C-based
    MCP23017. The potentiometer moved from GPIO7 to GPIO1 (ADC1_CH0).
    This eliminates the I²C dependency entirely.
    [MidiSynth.ino, build.py, config.h]
2026-08-30 Fix preset switch and button pin mapping to match hardware wiring
    The button is physically on GPIO14, and the preset switches are
    SW1=GPIO13 (bit0), SW2=GPIO12 (bit1), SW3=GPIO11 (bit2),
    SW4=GPIO10 (bit3), which differs from the previously assumed layout
    (button on GPIO10, switches on GPIO11-14).
    Update the PIN_* defines in src/config.h (synced to MidiSynth.ino
    via build.py), the GPIO interrupt log message, and the wiring
    documentation in README.md and 元件连接关键信息.md.
    [MidiSynth.ino, config.h]
2026-08-30 Add PCB project and Gerber files
    Include the JLCPCB EDA project (ProPrj_MIDI ESP32 .epro2) and
    the 2026-08-30 Gerber manufacturing output under PCB/.
2026-09-15 Remove dead mcp23017.inc and rename stale MCP23017 section
    Commit 134e108 replaced the MCP23017 I2C expander with direct GPIO, but left behind a dead driver file and a section name that no longer matched reality.
    - Delete src/mcp23017.inc: it is absent from build.py's ORDER list and nothing references initMCP23017, readMCP23017_GPIOB, or the MCP_* register constants. Regenerating MidiSynth_combined.cpp yields a byte-identical file, confirming it was already outside the build.
    - Rename the "MCP23017 开关映射" sync section to "预设开关引脚映射" in both build.py's SYNC_MAP and MidiSynth.ino, so the name matches the config.h section it actually mirrors.
    - Drop the "<Wire.h>" special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
    [MidiSynth.ino, build.py]
